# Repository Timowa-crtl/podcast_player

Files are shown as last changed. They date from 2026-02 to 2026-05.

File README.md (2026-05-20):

# KnobFM

Turn your Raspberry Pi into a tactile podcast and music player. Assign your podcasts and albums to fixed knob positions — turn to select, flip to play.

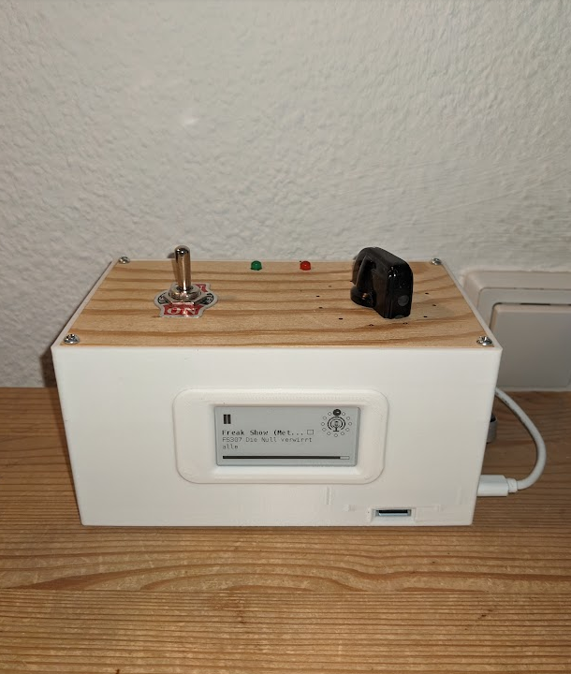
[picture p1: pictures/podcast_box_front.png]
frontview of 3D-printed enclosure


## How it works

- A **12-position rotary knob** selects one of up to 12 podcast feeds (Podcast mode) or up to 12 album folders (Music mode).
- A **3-position mode switch** toggles between **Podcast / Paused / Music**.
- Playback position is **auto-saved**, so switching modes or rebooting resumes where you left off.
- Audio plays through **VLC → ALSA** out of the Pi's 3.5 mm jack.
- Two **status LEDs** show what the player is doing (green = playing or activity, red = warning/error).
- New podcast episodes are fetched **hourly**.
- An optional **Waveshare 2.13″ e-ink display** shows the current podcast/album, episode title, and a progress bar.

## Hardware

The player needs:

- A Raspberry Pi (3 B/B+, 2 B, or 1 B+)
- A 12-position rotary switch (one GPIO per position, active-low)
- A 3-position toggle switch for the mode
- Two LEDs (red + green) with current-limiting resistors
- _(Optional)_ a Waveshare 2.13″ V2/V3 e-ink HAT

See:

- **[HARDWARE.md](HARDWARE.md)** — full bill of materials (Pi model, switches, LEDs, e-ink, enclosure, wiring supplies)
- **[WIRING.md](WIRING.md)** — GPIO pin assignments for the rotary switch, mode switch, LEDs, and optional e-ink display

**Audio output:** My recommended setup is a 3.5 mm in-car FM transmitter plugged into the Pi's aux output, broadcasting to a nearby FM radio.

## Enclosure

A 3D-printed enclosure designed for this project. The enclosure includes a mounting point and port cutouts. The lid features cutouts for the 3-way switch, R26 turning knob, and two LEDs.

Download the STL files from **[Thingiverse](https://www.thingiverse.com/thing:7228464)**, or grab them from [`enclosure/`](enclosure/).

## Installation

1. **Clone the repository**

   ```bash
   git clone https://github.com/Timowa-crtl/podcast_player.git
   cd podcast_player
   ```

2. **Install system dependencies**

   ```bash
   sudo apt update
   sudo apt install vlc
   ```

3. **Install Python packages** (system-wide via apt)

   ```bash
   sudo apt install python3-requests python3-schedule python3-vlc python3-pil python3-rpi.gpio
   ```

   If `python3-schedule` is unavailable on your Raspberry Pi OS release, fall back to `sudo pip install schedule`.

4. **(Optional) E-ink display setup**
   - Enable SPI: `sudo raspi-config` → Interface Options → SPI → Enable
   - Install extras: `sudo apt install python3-spidev python3-numpy`
   - The `waveshare_epd` driver is vendored in this repo — no separate install needed.
   - If `PIL` or `waveshare_epd` is missing, the display is silently disabled and the rest of the player works normally.

## Configuration

Edit `config.json` to customize your podcasts, albums and settings.

## Usage

### Run the player

```bash
python3 main.py                  # start the player (Ctrl+C to stop)
```

### Inspect state

```bash
python3 status.py
```

### Hardware smoke tests

Run these directly on the Pi to verify wiring:

```bash
python3 hardware.py          # poll the rotary + mode switch, prints state to stdout
python3 led_controller.py    # cycle through every LED state
```

## Autostart with systemd

To run the player on boot, create a systemd service. Replace `<your-user>` with your Linux username (e.g. `pi`).

1. Create `/etc/systemd/system/podcast.service` with:

   ```ini
   [Unit]
   Description=Podcast Player
   After=network.target

   [Service]
   ExecStart=/usr/bin/python3 -u /home/<your-user>/podcast_player/main.py
   WorkingDirectory=/home/<your-user>/podcast_player
   User=<your-user>
   Restart=always

   StandardOutput=append:/home/<your-user>/podcast_player/podcast.log
   StandardError=append:/home/<your-user>/podcast_player/podcast.log

   [Install]
   WantedBy=multi-user.target

   ```

2. Reload systemd:

   ```bash
   sudo systemctl daemon-reload
   ```

3. Enable autostart:

   ```bash
   sudo systemctl enable podcast.service
   ```

4. Start service:

   ```bash
   sudo systemctl start podcast.service
   ```

5. View logs:

   ```bash
   tail -f ~/podcast_player/podcast.log
   ```

## Gallery

frontview of 3D-printed enclosure
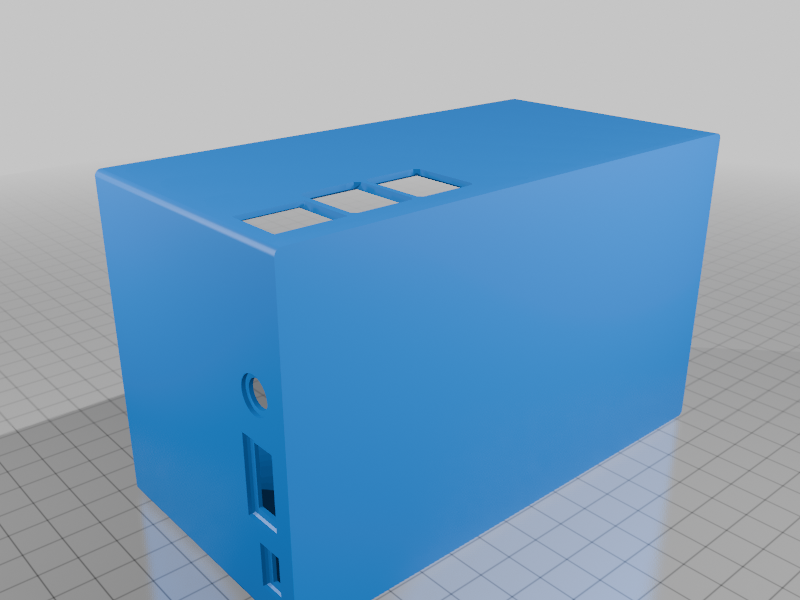
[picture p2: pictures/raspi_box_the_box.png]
enclosure box render

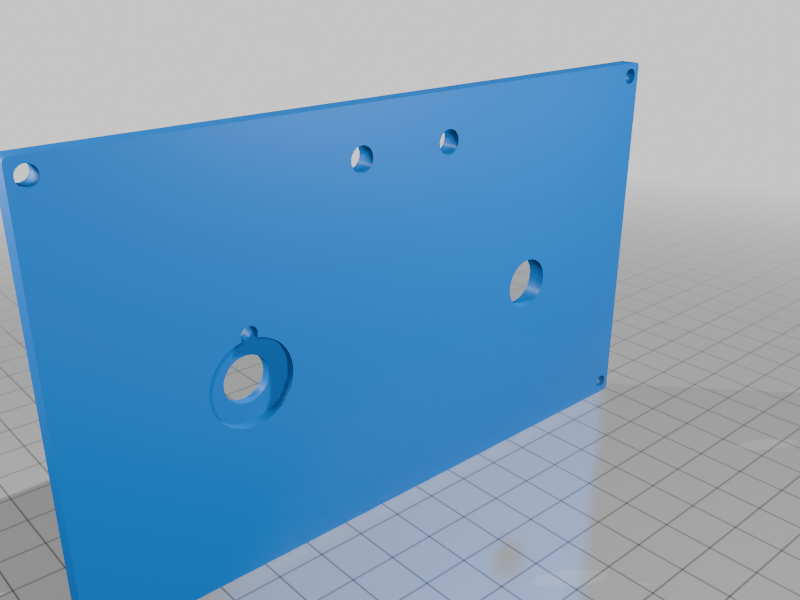
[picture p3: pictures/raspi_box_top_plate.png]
top plate render

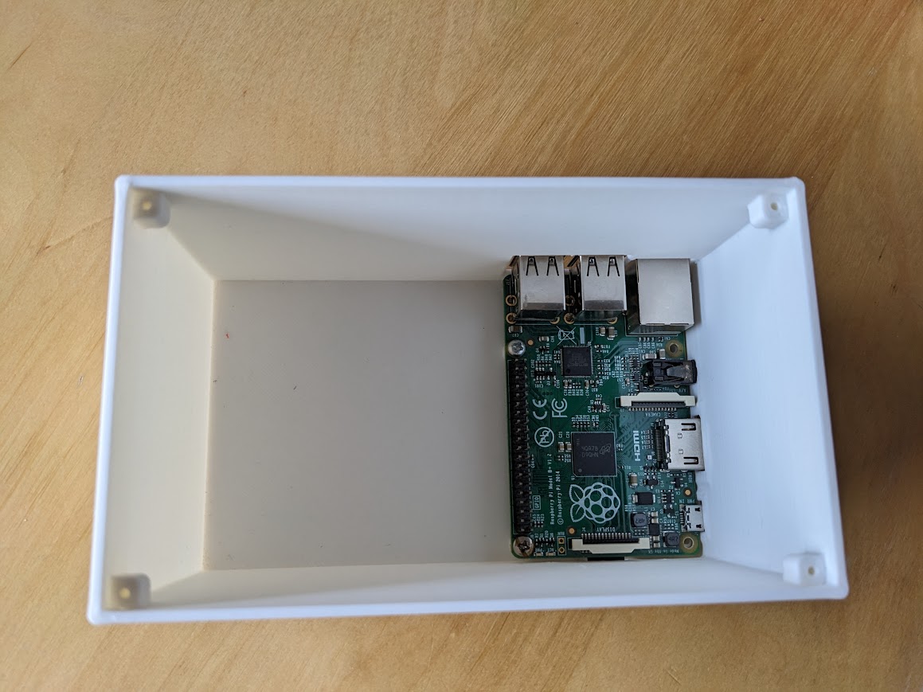
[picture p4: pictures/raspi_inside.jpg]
Raspberry Pi wired inside the enclosure

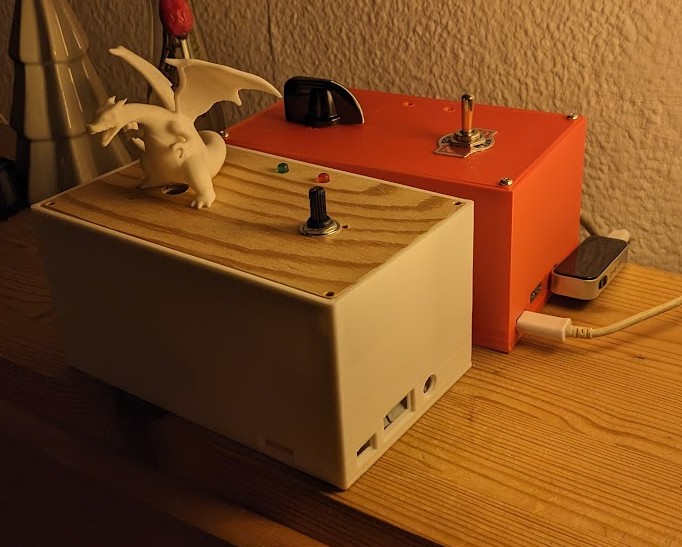
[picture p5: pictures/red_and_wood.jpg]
finished player, red knob with wood top

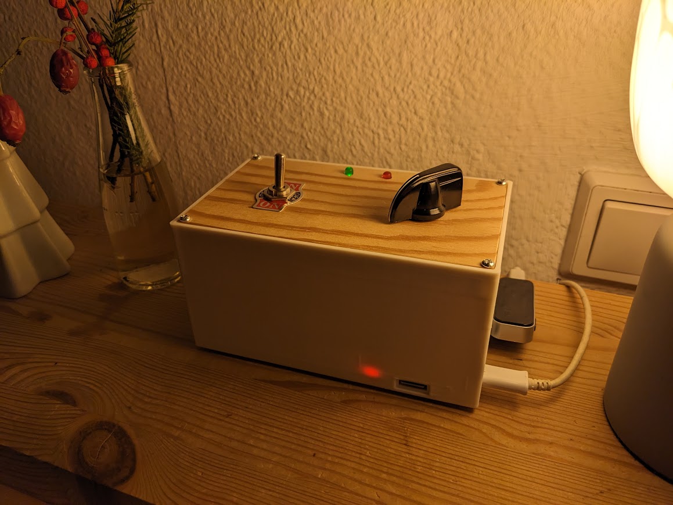
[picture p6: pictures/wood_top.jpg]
wood top plate detail


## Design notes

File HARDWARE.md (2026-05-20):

# Hardware

Bill of materials for building the player. For how to wire them up, see [WIRING.md](WIRING.md).

## Compute

- Raspberry Pi 3 B, Pi 2 B, Pi 1 B+. Any model with a 40-pin GPIO header should work.
- **MicroSD card** — 16 GB or larger

## Controls

### Rotary Switch (podcast / album selector)

- **RS26 1-pole 12-position rotary switch**, panel mount, 6 mm shaft
- **Knob** — R26-style aluminum knob with 6 mm collet (matches the enclosure cutout)

### Mode Switch (podcast / paused / music)

- **3-position SPDT toggle switch**, center-off (ON-OFF-ON), panel mount

### Status LEDs

- **2× 3 mm LEDs** — one red, one green
- **resistor** — 1000 Ω 

### Audio Output (recommended)

- **3.5 mm in-car FM transmitter** — plugs into the Pi's 3.5 mm aux output and broadcasts on an FM frequency you tune your radio to. This my recommended setup. Feel free to adapt!

### E-Ink Display (optional)

- **Waveshare 2.13" e-Paper HAT (V4)** — 250×122, SPI interface
  - The vendored driver in `waveshare_epd/` targets the V4 specifically; older V1/V2/V3 panels might need a different driver

## Connections & Prototyping

- **T-type GPIO breakout board for Raspberry Pi** — with 40-pin ribbon cable, to bring the Pi header onto a breadboard or prototype board
- **Breadboard** - must fit breakout board and cables and fit into the enclosure
- **Dupont jumper wires** — 20-pin assorted set with M-M, F-M, and F-F (Pi header → breakout → switches/LEDs)

## Enclosure

- **3D-printed case** with cutouts for the rotary knob, 3-position switch, and two LEDs
  - STL files: [thingiverse.com/thing:7228464](https://www.thingiverse.com/thing:7228464)
  - Compatible with Pi 3 B/B+, Pi 2 B, Pi 1 B+

## Wiring

See [WIRING.md](WIRING.md) for the full GPIO pin assignment table.

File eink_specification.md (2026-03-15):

# E-Ink Display Specification

## Overview

Add a Waveshare 2.13" V4 e-ink display (250×122 pixels, 1-bit black/white) to show playback status. The display is **completely optional** — the player works fine without it, same as GPIO.

---

## Hardware

- **Model**: Waveshare 2.13" V4 (epd2in13_V4)
- **Resolution**: 250×122 pixels, landscape orientation
- **Colors**: 1-bit (black and white only)
- **Interface**: SPI

---

## Screen Layout

There is **one layout** used for both playing and paused states, in both podcast and music modes. The only difference between playing and paused is the icon (▶ vs ⏸).

```
┌──────────────────────────────────────────┐
│                                  · · ·   │
│                                ·       · │
│                                ·  icon · │
│                                ·       · │
│                                  · ● ·   │
│                                          │
│ ▶ LANZ & PRECHT ☐                       │
│                                          │
│ Ausgabe 421: Über die Zukunft            │
│ der Arbeit in Deuts...                   │
│                                          │
│ ████████████████░░░░░░░░░░░░░░░░░░░░░░░ │
└──────────────────────────────────────────┘
```

### Elements top to bottom

1. **Dot circle with mode icon** (top-right): 12 dots in a circle representing the rotary knob positions, with the current position shown as a larger filled dot. A mode icon (podcast or music) is centered inside the dot circle.

2. **Name line**: play (▶) or pause (⏸) icon + podcast name or album display name (bold, truncated to fit) + completion checkbox (☐/☑) immediately after the name text.

3. **Title area**: episode title or track filename, regular weight, up to 2 lines, word-wrapped, truncated with `...` if needed.

4. **Progress bar**: full display width with margins, outlined rectangle with black fill representing progress. No text/numbers.

---

## Dot Circle (Knob Position Indicator)

A circle of 12 dots mirroring the physical 12-position rotary knob.

### Positioning

- Top-right corner of the display
- ~44px diameter (22px radius)
- Mode icon centered inside the circle

### Dot orientation

Dots are numbered 1–12 clockwise, starting from the bottom-left:

- **Position 1**: 7 o'clock (bottom-left)
- **Position 6**: 12 o'clock (top)
- **Position 12**: 6 o'clock (bottom)

### Dot rendering

- Inactive positions: small filled dot (~2px radius)
- Active position: larger filled dot (~4px radius)

### Center icon

- Podcast mode: `icons/podcast.png` (microphone with broadcast arcs)
- Music mode: `icons/music.png` (beamed eighth notes)
- Pre-made 1-bit PNGs, resized to 24×24px, stored in `icons/` directory
- If icon file is missing: skip silently, no crash

---

## Completion Checkbox

- Small checkbox (☐ unchecked / ☑ checked) drawn inline on the name line, immediately after the name text with a small gap
- ☑ = this album/podcast episode has been played to the end at least once
- ☐ = not yet completed
- The checkbox reduces the available width for the name text — name is truncated to leave room

---

## Play / Pause Icon

- **Playing**: filled triangle pointing right (▶)
- **Paused**: two vertical bars (⏸)
- Drawn at the left edge of the name line, before the name text

---

## Progress Bar

- Full display width minus left/right margins
- Thin outlined rectangle with black fill from the left representing progress (0.0–1.0)
- If duration is unknown: empty bar (outline only)

---

## Text Rendering

- **Font**: monospace TTF (DejaVu Sans Mono preferred, falls back to Liberation Mono, FreeMono, then Pillow default)
- **Name line**: bold, ~11px
- **Title lines**: regular, ~10px
- **Truncation**: names and titles truncated with `...` if they exceed available width
- **Title wrapping**: up to 2 lines, word-wrapped, last line truncated if needed
- **No scrolling, no animation, all text is static**

---

## Display States

| State | Play/pause icon | Name | Title | Checkbox | Progress | Dot circle icon |
|---|---|---|---|---|---|---|
| Podcast playing | ▶ | podcast name | episode title | completion state | position/duration | podcast |
| Podcast paused | ⏸ | podcast name | episode title | completion state | frozen | podcast |
| Music playing | ▶ | album display name | track filename | completion state | position/duration | music |
| Music paused | ⏸ | album display name | track filename | completion state | frozen | music |
| Album completed | ⏸ | album display name | last track filename | ☑ | full | music |
| No episode | ⏸ | podcast name | "Error - no episode found" | ☐ | empty | podcast |
| Blank | — | — | — | — | — | — |

### Boot / no content → blank

On startup, one full refresh to clear display to white. Stays blank until the first mode change that has content to show.

### Paused with no prior playback

If the player has never played anything in this session, display stays blank. First play action triggers the first draw.

---

## Update Triggers

| Event | Display action |
|---|---|
| Mode switch to PLAYING | Redraw with ▶ + podcast info |
| Mode switch to MUSIC_MODE | Redraw with ▶ + album info |
| Mode switch to PAUSED | Redraw with ⏸, keep current content |
| Knob turn while playing | Redraw with new podcast/album |
| Knob turn while paused | Redraw with preview of new selection |
| Progress update (every 30s) | Redraw with updated progress |
| Track change (music) | Redraw with new track info |
| Album completed (music) | Show ☑ + full progress bar |
| No episode available | Show name + error title |
| RSS check running/completed | No display change (LED handles this) |
| Shutdown | Put display to sleep |

---

## Refresh Strategy

- **Partial refresh** for all normal updates (~0.3s)
- **One full refresh on startup** to clear ghosting
- **Periodic full refresh** every ~50 partial refreshes to reduce ghosting buildup

---

## Display Controller API

```python
class EinkDisplay:
    """E-Ink display controller. Optional — disabled if hardware missing."""

    def __init__(self, icons_dir: str = "icons"):
        """Init display. Loads icon PNGs from icons_dir.
        Sets self.available = False if libs/hardware missing."""

    def clear(self):
        """Full refresh to white. Called once on startup."""

    def show(self, name: str, title: str, progress: float,
             knob_position: int, is_playing: bool, is_completed: bool,
             icon: Optional[str] = None):
        """
        Draw the screen. Single method for all states.

        Args:
            name:           podcast name or album display name
            title:          episode title or track filename
            progress:       0.0 to 1.0 (progress bar fill)
            knob_position:  1-12 (active dot in the circle)
            is_playing:     True = ▶, False = ⏸
            is_completed:   True = ☑, False = ☐
            icon:           "podcast", "music", or None
        """

    def show_blank(self):
        """Clear to white (partial refresh)."""

    def cleanup(self):
        """Put display to sleep. Called on shutdown."""
```

One render method. Callers pass data, display draws it.

---

## Graceful Degradation

Same pattern as `LEDController` and `HardwareController`:

- If Pillow or the Waveshare library is missing, or hardware init fails, `self.available = False`
- Every public method is a no-op if `self.available` is False
- No crashes, no errors — just silently disabled

---

## Integration Points

### podcast_player.py

Display updated from the main controller:

- `switch_to_podcast()` → `display.show(..., icon="podcast")`
- `switch_to_album()` → `display.show(..., icon="music")`
- `pause()` → `display.show(...)` with current info, `is_playing=False`, same icon as last active mode
- `handle_switch_change()` knob turn while paused → `display.show(...)` with preview info
- `_on_track_ended()` → redraw with new track info
- Main loop every 30s during playback → `display.show(...)` with updated progress

### Progress update in main loop

```python
# In run(), alongside existing polling:
if self.audio.is_playing() and time.time() - last_display_update > 30:
    self._update_display()
    last_display_update = time.time()
```

---

## Demo Mode

Run `python eink_display.py` to cycle through display states on the real e-ink screen. **Requires hardware** — exits immediately if no display is detected.

- Cycles 8 screens (20 seconds each): podcast playing, podcast paused (completed), music playing, music paused, album completed, no episode error, long name truncation, position 12 test
- Loops until Ctrl+C
- Blank screen shown between cycles
- On exit: clears display and puts it to sleep

---

## Edge Cases

### Album completed

When the last track finishes, the player goes silent. The display stays on and shows the completed album with ☑ checkbox, album name, last track filename, and a **full progress bar**. Remains until the user switches away.

### No episode available

If a podcast position has no downloaded episode, the display shows the podcast name with title `"Error - no episode found"` and an empty progress bar.

### Music track change

When one track ends and the next begins, the display briefly shows the **completed track with a full progress bar** (one refresh cycle), then redraws with the new track's filename and an empty progress bar.

### RSS check

Display ignores RSS checks entirely. LED handles that feedback.

---

## File Summary

| File | Change | Description |
|---|---|---|
| `eink_display.py` | **NEW** | Display controller: rendering, refresh, layout, demo |
| `icons/podcast.png` | **NEW** | 1-bit podcast icon (24×24px, white background) |
| `icons/music.png` | **NEW** | 1-bit music icon (24×24px, white background) |
| `podcast_player.py` | MODIFIED | Call `display.show()` on mode/knob/progress changes |
| `requirements.txt` | MODIFIED | Add `Pillow` (waveshare lib is vendored) |

---

## Scope Exclusions

- No clock
- No scrolling text
- No animations
- No overview/list screen
- No configuration options for display
- No different layouts per mode (one layout fits all)
- No track number display (just filename)
- No display feedback for RSS checks, warnings, or errors (LED handles those)
- No PNG export in demo mode — demo requires real hardware

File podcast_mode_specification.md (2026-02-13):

# Podcast Mode Specification

## Overview

The Raspberry Pi Podcast Player supports up to 12 podcast feeds mapped to the 12-position rotary knob. In podcast mode, the player fetches episodes via RSS, downloads audio files, and plays them with persistent position tracking. Episodes are checked periodically and old ones are cleaned up automatically.

---

## Configuration

### config.json

```json
{
  "podcasts": [
    {
      "name": "Logbuch Netzpolitik",
      "rss_url": "https://logbuch-netzpolitik.de/feed/mp3"
    },
    {
      "name": "Radiolab",
      "rss_url": "https://feeds.simplecast.com/EmVW7VGp"
    }
  ],
  "episodes_dir": "episodes",
  "max_episodes_per_podcast": 2,
  "check_interval_hours": 1,
  "position_save_interval": 1,
  "download_timeout": 30,
  "rss_timeout": 10,
  "debug_mode": false
}
```

- `podcasts`: list of up to 12 entries, mapped to knob positions 1–12 in order
  - `name`: required, display name
  - `rss_url`: required, RSS feed URL
- `episodes_dir`: where downloaded episodes are stored. **Default**: `episodes`
- `max_episodes_per_podcast`: max episodes kept per feed. **Default**: `2`
- `check_interval_hours`: how often to check RSS feeds. **Default**: `1`
- `position_save_interval`: seconds between position saves. **Default**: `5`
- `download_timeout`: seconds before download times out. **Default**: `30`
- `rss_timeout`: seconds before RSS fetch times out. **Default**: `10`
- `debug_mode`: enable verbose DEBUG-level logging. **Default**: `false`

### Validation

- `podcasts` must be present and non-empty
- Maximum 12 podcasts
- Each podcast must have `name` and `rss_url`

---

## RSS Feed Handling

### Fetching

- Standard HTTP GET with `User-Agent: PodcastPlayer/1.0`
- Supports both RSS 2.0 (`<item>`) and Atom (`<entry>`) feeds
- Timeout controlled by `rss_timeout`

### Episode extraction

From each feed item, extract:

- **Title**: from `<title>` element. Whitespace-collapsed, truncated to 100 chars
- **Audio URL**: from `<enclosure url="...">` (RSS) or `<link rel="enclosure" href="...">` (Atom)
- **GUID**: from `<guid>` or `<id>`. Falls back to audio URL if missing

Items without an enclosure URL are skipped.

### Check schedule

- First check runs immediately on startup
- Subsequent checks run every `check_interval_hours` via the `schedule` library
- Checks also run pending in the main loop (polled every 100ms)

---

## Episode Downloading

### File naming

Episodes are saved as `episode_<hash>.mp3` where `<hash>` is the first 12 hex chars of the MD5 of the episode GUID. This gives stable filenames across restarts.

### Storage layout

```
episodes/
  podcast_1/
    episode_abc123def456.mp3
  podcast_2/
    episode_789012345678.mp3
```

Each podcast gets its own subdirectory under `episodes_dir`.

### Download behavior

- Streamed download in 8KB chunks
- Progress logged at DEBUG level every 10%
- If the file already exists (same GUID hash), download is skipped
- Partial downloads are deleted on failure

### Cleanup

After updating episodes for a podcast, any files in that podcast's directory that aren't in the current episode list are deleted. This keeps storage bounded to `max_episodes_per_podcast` files per feed.

---

## Playback Behavior

### Basic flow

1. Switch to Podcast mode → start playing the podcast at the current knob position
2. Plays the current episode from the saved position
3. One episode per podcast at a time (controlled by `current_index`)

### Resume

- Switching away and back to a podcast **resumes exact position**
- Resume rewinds 2 seconds for context (`pos = max(0, ep["position"] - 2)`)
- Position saved at `position_save_interval` via a background thread in `AudioPlayer`
- If the episode is within 10 seconds of the end, it restarts from the beginning

### Switching podcasts

- Turning the knob while in Podcast mode → **immediately stop current, start new podcast**
- If knob is on position 3 and user switches from Music/Pause to Podcast → **immediately start podcast 3**

### Error handling

- No episodes downloaded yet → log warning, stay silent, LED off
- Episode file missing from disk → log error, stay silent, LED off
- RSS fetch timeout or parse error → log warning/error, skip that feed
- Download timeout or HTTP error → log error, clean up partial file, skip

---

## State Storage

Stored in `state.json` under the `podcasts` namespace.

```json
{
  "version": 2,
  "podcasts": {
    "podcast_1": {
      "episodes": [
        {
          "title": "Episode Title",
          "guid": "unique-episode-id",
          "file": "episode_abc123def456.mp3",
          "position": 123.4,
          "last_played": "2025-01-15T10:30:00",
          "completed": false
        }
      ],
      "current_index": 0,
      "total_time": 3600
    }
  },
  "music": { ... },
  "last_check": 1705312200
}
```

- `episodes`: ordered list of downloaded episodes
- `current_index`: which episode is active (0-based)
- `total_time`: cumulative listening time in seconds (incremented by 1 per save tick)
- `position`: seconds into the episode
- `completed`: true when episode finished
- `last_check`: Unix timestamp of last RSS check (shared across all feeds)

### Position save throttling

`StateManager.save()` is throttled to at most once per second unless `force=True`.

---

## Hardware / Switch Mapping

### 3-position mode switch

| Position | Behavior |
| --- | --- |
| Play | Play podcast at current knob position |
| Center | Paused (both modes) |
| Music | Play music (see music_mode_specification.md) |

### 12-position rotary knob

- In Podcast mode: selects podcast 1–12
- Debounced: requires 3 stable reads and 200ms minimum between changes

### LED behavior

| State | LEDs |
| --- | --- |
| Playing | Green solid  |
| Paused | Off |
| Checking RSS | Green blink  |
| Downloading  | Green blink  |
| Warning | Red 3× blink |
| Error | Red 5× blink |

---

## Software-only Mode (no GPIO)

Without GPIO (e.g. running on a desktop), the hardware controller returns `PAUSED` with no podcast index. Podcast mode is not reachable without hardware or manual code changes.

---

## Status Display (status.py)

```
📻 Podcasts (12):
   1. Logbuch Netzpolitik
   2. Fest und Flauschig
   ...

📚 Podcast Episodes:

   Logbuch Netzpolitik:
      ▶️ 1. LNP500: Jubiläumsfolge         | 1h 23m 45s | 45.2 MB
      ✅ 2. LNP499: Alte Folge              | 0s         | 38.1 MB

💾 Storage: 24 files, 1234.5 MB in episodes
💿 Disk: 12.3 GB free / 32.0 GB (62% used)
```

Markers: `▶️` = current episode, `✅` = completed, blank = not yet played.

---

## Scope

- One episode plays at a time per podcast (no playlist/queue)
- No episode skipping via hardware
- No per-podcast volume control
- No streaming — episodes are fully downloaded before playback
- mp3 only (determined by RSS enclosure)

---

## File Summary

| File | Role |
| --- | --- |
| `config.py` | Loads and validates `config.json` |
| `config.json` | Podcast list, directories, timeouts |
| `podcast_manager.py` | RSS fetching, episode downloading, cleanup |
| `audio_player.py` | VLC playback with position tracking |
| `state_manager.py` | Persistent JSON state for positions and metadata |
| `podcast_player.py`  | Main controller: ties hardware → podcast/music → audio |
| `hardware.py` | GPIO rotary switch and mode switch reading |
| `led_controller.py`  | Red/green LED patterns for status feedback |
| `status.py` | CLI status display tool |
| `main.py` | Entry point, signal handling, startup/shutdown |
| `utils.py` | Logging, formatting helpers |

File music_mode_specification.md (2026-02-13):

# Music Mode Specification

## Overview

Add a music playback mode to the Raspberry Pi Podcast Player. The 3-position switch becomes: **PlayPodcast / Pause / PlayMusic**. In music mode, each of the 12 rotary knob positions selects an album folder and plays it sequentially from track 1 to end, remembering position across switches.

---

## Configuration

### config.json additions

```json
{
  "music_dir": "/home/tweckerle/music",
  "albums": [
    { "folder": "Kraftklub - Mit K.-2012" },
    { "folder": "Linkin Park - Meteora", "name": "Meteora" },
    { "folder": "Peter Fox - Stadtaffe" }
  ]
}
```

- `music_dir`: base directory for album folders. **Default**: `~/music`
- `albums`: list of up to 12 entries, mapped to knob positions 1-12 in order
- `folder`: required, relative to `music_dir`
- `name`: optional display name override. **Default**: folder name

### Album discovery fallback

If `albums` is **not present or empty** in config.json, auto-discover by taking the first 12 subfolders of `music_dir` sorted alphabetically. If `albums` is configured, use only those — no auto-discovery.

### Config reading

Music config is **re-read from config.json on every knob selection** (not cached at startup). This allows editing config without restarting the player.

---

## File Handling

- **Format**: mp3 only (`.mp3` extension, case-insensitive)
- **Sorting**: natural/numeric sort (e.g., `2-song.mp3` before `10-song.mp3`)
- **Subfolder handling**: top-level files only, no recursion into subdirectories
- **Track discovery**:
  - **Fresh start / album reset**: scan folder for all mp3 files at play time
  - **Resuming saved position**: use remembered track list, do not re-scan

---

## Playback Behavior

### Basic flow

1. Switch to Music mode → start playing the album at the current knob position
2. Tracks play sequentially from track 1 to last track
3. Standard gap between tracks (no crossfade, no gapless)
4. Track changes logged at INFO level: `"Now playing track 3/12: filename.mp3"`

### Resume

- Switching away and back to an album **resumes exact track + position within track**
- Switching from Pause to Music **resumes** where it left off
- Position saved at same `position_save_interval` as podcasts (configurable, currently 1s)
- Resume rewinds 2 seconds (same as podcast behavior)

### Album completed

- After last track ends → **stop playback, go silent**
- Album marked as completed in state
- When a completed album is selected again (or switched back to) → **reset to track 1, position 0, re-scan folder for mp3 files**

### Switching albums

- Turning knob while in Music mode → **immediately stop current album, start new album**
- If knob is on position 7 and user switches from Podcast to Music → **immediately start album 7**

### Error handling

- Missing/empty album folder → log warning, play nothing
- Corrupted/unplayable mp3 → log warning, mark track as completed, skip to next track
- If all tracks fail → album goes silent (treated as completed)

### Positions 9-12 with fewer albums

- If fewer than 12 albums configured/discovered → unassigned positions do nothing (silence, log warning)

---

## State Storage

Stored in **same `state.json`** as podcasts, namespaced with `music_` prefix.

```json
{
  "podcasts": { ... },
  "music_1": {
    "folder": "Kraftklub - Mit K.-2012",
    "tracks": ["01-song.mp3", "02-song.mp3"],
    "current_track": 1,
    "position": 45.2,
    "completed": false,
    "total_time": 3600
  },
  "music_5": { ... }
}
```

- `folder`: the folder name at time of last play (to detect config changes)
- `tracks`: ordered list of mp3 files from last scan
- `current_track`: index into `tracks` (0-based)
- `position`: seconds into current track
- `completed`: true when last track finished
- `total_time`: cumulative listening time

---

## Hardware / Switch Mapping

### 3-position mode switch (updated)

| Position | Old behavior | New behavior |
|---|---|---|
| Play | Play podcast | **Play podcast** |
| Center | Paused | **Paused** (both modes) |
| Music | Lightshow | **Play music** |

### 12-position rotary knob

- In Podcast mode: selects podcast 1-12 (unchanged)
- In Music mode: selects album 1-12

### LED behavior (updated)

- Music mode uses **same LED behavior as podcast mode**:
  - Playing → green solid
  - Paused → off
- **Lightshow removed**

---

## Software-only mode (no GPIO)

Same behavior as podcast mode: falls back to PAUSED. Music mode not reachable without hardware (same limitation as current podcast mode).

---

## Status Display (status.py)

Show music mode info alongside podcast info:

```
🎵 Music Albums (3 configured, base: /home/tweckerle/music):
   1. Kraftklub - Mit K.-2012
      ▶️ Track 3/12 | 2m 15s | 01-intro.mp3
   2. Linkin Park - Meteora (Meteora)
      ✅ Completed
   3. Peter Fox - Stadtaffe
      (not started)
```

---

## Scope exclusions

- No track skipping (plays straight through)
- No per-mode volume control (system/VLC global volume)
- No crossfade or gapless playback
- No recursive subfolder scanning
- No file formats other than mp3

---

## Implementation constraints

- **Must not break existing podcast mode** — podcast mode is stable
- Reuse existing components where possible (`AudioPlayer`, `StateManager`, `LEDController`)
- Music state uses same `state.json`, same `position_save_interval`
- Music config re-read from `config.json` on each knob selection

---

## Implementation Summary

### Files changed

| File | Change | Description |
|---|---|---|
| `music_manager.py` | **NEW** | Album discovery, track scanning, config re-reading, natural sort |
| `audio_player.py` | MODIFIED | Added VLC `MediaPlayerEndReached` event → `has_ended()` method |
| `config.py` | MODIFIED | Added `music_dir`, `albums` properties + validation |
| `config.json` | MODIFIED | Added `music_dir`, `albums` fields |
| `state_manager.py` | MODIFIED | Added `music` namespace + `get_music`, `save_music`, `update_music_position`, `mark_music_completed`, `reset_music` methods |
| `podcast_player.py` | MODIFIED | Added music mode handling: `switch_to_album`, `_play_music_track`, `_advance_music_track`, end-of-track check in main loop |
| `led_controller.py` | MODIFIED | Removed lightshow, `MUSIC_MODE` → green solid (same as `PLAYING`) |
| `status.py` | MODIFIED | Added music albums section to status display |
| `hardware.py` | UNCHANGED | `SwitchState.MUSIC_MODE` already existed |
| `main.py` | UNCHANGED | No changes needed |
| `utils.py` | UNCHANGED | No changes needed |

### Key design decisions

1. **End-of-track detection**: VLC `MediaPlayerEndReached` event sets a `threading.Event`. Main loop polls `audio.has_ended()` every 100ms to advance tracks. Avoids complex callback threading.
2. **Config re-read**: `MusicManager._read_music_config()` reads `config.json` fresh on every knob selection. This is intentional — allows editing albums without restart.
3. **State namespacing**: Music state stored under `state["music"]["music_1"]` etc., separate from `state["podcasts"]`. Clean separation.
4. **Position callback routing**: Single `_save_position` callback checks `self._is_music_mode()` to route to podcast or music save logic.
5. **Podcast mode untouched**: All podcast logic paths remain identical. Music mode is additive only.

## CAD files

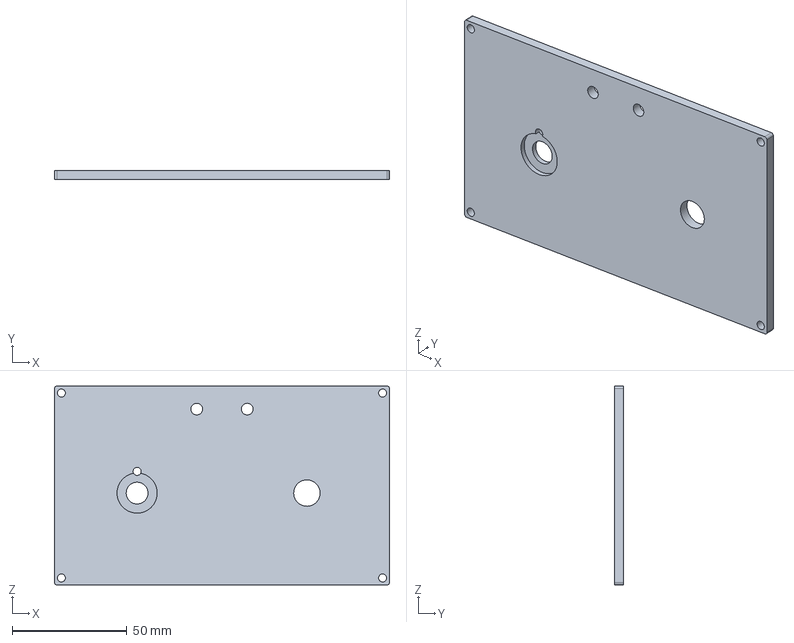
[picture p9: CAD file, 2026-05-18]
enclosure/raspi_box_base.FCStd
146.0 x 4.00 x 86.6 mm

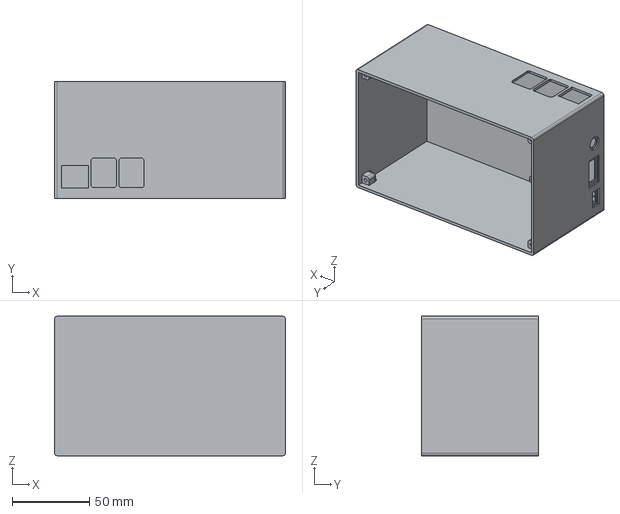
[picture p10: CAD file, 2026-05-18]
enclosure/raspi_box_the_box.step
150.0 x 76.0 x 90.6 mm

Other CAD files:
enclosure/raspi_box_top_plate.step
enclosure/raspi_box_the_box.stl
enclosure/raspi_box_top_plate.stl

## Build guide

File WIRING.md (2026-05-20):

# Wiring

All pin numbers are **BCM GPIO** (not physical header positions). Use a Raspberry Pi pinout reference (e.g. `pinout` command or [pinout.xyz](https://pinout.xyz)) to map BCM numbers to physical pins.

I used dupont wires (no soldering).

> ⚠️ **Disclaimer:** Please confirm pin positions against the source files: `hardware.py`, `led_controller.py`, and `eink_display.py`.

## 12-Position Rotary Switch

One common pole wired to **GND**. Each of the 12 positions connects to one GPIO pin:

| Position | BCM GPIO |
| --- | --- |
| 1 | 4 |
| 2 | 18 |
| 3 | 22 |
| 4 | 23 |
| 5 | 9 |
| 6 | 21 |
| 7 | 5 |
| 8 | 6 |
| 9 | 12 |
| 10 | 13 |
| 11 | 16 |
| 12 | 20 |

## 3-Position Mode Switch

Common pole to **GND**. The two outer positions connect to GPIO pins; the center position leaves both pins floating (interpreted as PAUSED).

| Position | BCM GPIO | Meaning |
| --- | --- | --- |
| Left | 7 | Podcast play |
| Center | — | Paused |
| Right | 27 | Music mode |

## LEDs

You can wire both LED cathodes (short leg) through a single **1000 Ω resistor** to **GND**. Anodes (long leg) connect directly to their GPIO pins.

| LED | BCM GPIO |
| ----- | --- |
| Red | 26 |
| Green | 19 |

## E-Ink Display (Waveshare 2.13" V4) — optional

Requires SPI enabled (`sudo raspi-config` → Interface Options → SPI).

| Display Pin | BCM GPIO / Function |
| --- | --- |
| VCC | 3.3V |
| GND | GND |
| DIN (MOSI)  | 10 (SPI MOSI) |
| CLK (SCK) | 11 (SPI SCLK) |
| CS | 8 (SPI CE0) |
| DC | 25 |
| RST | 17 |
| BUSY | 24 |

## Audio Output

Audio is played through ALSA — use the Pi's 3.5mm jack.

## Test the Wiring

```bash
python3 hardware.py      # Live readout of switch states
python3 led_controller.py # Cycle through LED patterns
```

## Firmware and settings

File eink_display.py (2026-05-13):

"""E-Ink display controller for Waveshare 2.13" V4 (250x122, 1-bit).

Layout (see specs.md for full details):
  - Top-left: play/pause icon (own line)
  - Top-right: dot circle (12 dots mimicking rotary knob) with mode icon centered inside
  - Name line: name (bold) + completion checkbox, width restricted to avoid dot circle
  - Title: up to 2 lines, word-wrapped, truncated with '...'
  - Progress bar: full width, bottom

Completely optional — gracefully disabled if hardware or libs are missing.
"""

import math
import os
import sys
import time
from typing import Optional

from utils import log

# --- Dependency detection -------------------------------------------------

_libdir = os.path.join(os.path.dirname(os.path.realpath(__file__)), "lib")
if os.path.exists(_libdir):
    sys.path.insert(0, _libdir)

try:
    from PIL import Image, ImageDraw, ImageFont

    PIL_AVAILABLE = True
except ImportError:
    PIL_AVAILABLE = False

try:
    from waveshare_epd import epd2in13_V4

    EPD_AVAILABLE = True
except ImportError:
    EPD_AVAILABLE = False

DISPLAY_AVAILABLE = PIL_AVAILABLE and EPD_AVAILABLE

if not PIL_AVAILABLE:
    log("DEBUG", "Pillow not available — e-ink display disabled")
if not EPD_AVAILABLE:
    log("DEBUG", "waveshare_epd not available — e-ink display disabled")


# --- Display dimensions ---------------------------------------------------

WIDTH = 250
HEIGHT = 122

# --- Layout constants (pixels) --------------------------------------------

MARGIN = 7

# Dot circle (top-right) — bigger radius, bigger dots
DOT_CIRCLE_RADIUS = 25
DOT_CIRCLE_CX = WIDTH - MARGIN - DOT_CIRCLE_RADIUS - 2
DOT_CIRCLE_CY = MARGIN + DOT_CIRCLE_RADIUS + 2
DOT_RADIUS_INACTIVE = 3
DOT_RADIUS_ACTIVE = 5

# Play/pause icon (top-left, own line above the name)
PLAY_ICON_SIZE = 20
PLAY_ICON_X = MARGIN
PLAY_ICON_Y = 14

# Name line (below play/pause icon, tight gap)
NAME_Y = 46

# Title (below name)
TITLE_Y = 62
TITLE_LINE2_Y = 78

# Progress bar
BAR_Y = 106
BAR_HEIGHT = 6
BAR_WIDTH = WIDTH - 2 * MARGIN

# Completion checkbox
CHECK_SIZE = 10
CHECK_GAP = 5

# Font sizes — slightly larger for readability
FONT_SIZE_NAME = 14
FONT_SIZE_TITLE = 12

# Full refresh interval (partial refreshes between full refreshes)
FULL_REFRESH_INTERVAL = 100


class EinkDisplay:
    """E-Ink display controller. Optional — disabled if hardware missing."""

    def __init__(self, icons_dir: str = "icons"):
        self.available = False
        self._partial_count = 0
        self._icons = {}
        self._font_path: Optional[str] = None

        if not DISPLAY_AVAILABLE:
            log("DEBUG", "E-ink display not available")
            return

        try:
            self.epd = epd2in13_V4.EPD()
            self.epd.init()
            self.epd.Clear(0xFF)
            self.available = True
            log("INFO", "E-ink display initialized (250x122)")
        except Exception as e:
            log("WARNING", f"E-ink init failed: {e}")
            return

        # Load fonts
        self._font_name = self._load_font(FONT_SIZE_NAME, bold=True)
        self._font_title = self._load_font(FONT_SIZE_TITLE)

        # Load mode icons from PNG files
        self._load_icons(icons_dir)

    # --- Font loading ------------------------------------------------------

    def _load_font(self, size: int, bold: bool = False):
        """Load a monospace TTF font, falling back to Pillow default."""
        candidates = []

        if bold:
            candidates += [
                "/usr/share/fonts/truetype/dejavu/DejaVuSansMono-Bold.ttf",
                "/usr/share/fonts/truetype/liberation/LiberationMono-Bold.ttf",
                "/usr/share/fonts/truetype/freefont/FreeMonoBold.ttf",
            ]

        candidates += [
            "/usr/share/fonts/truetype/dejavu/DejaVuSansMono.ttf",
            "/usr/share/fonts/truetype/liberation/LiberationMono-Regular.ttf",
            "/usr/share/fonts/truetype/freefont/FreeMono.ttf",
        ]

        for path in candidates:
            if os.path.exists(path):
                try:
                    font = ImageFont.truetype(path, size)
                    if self._font_path is None:
                        self._font_path = path
                    return font
                except Exception:
                    continue

        log("DEBUG", f"No TTF font found, using Pillow default (size={size})")
        return ImageFont.load_default()

    # --- Icon loading ------------------------------------------------------

    # Icon size — PNGs are resized to this square dimension to fit inside the dot circle
    ICON_SIZE = 35

    def _load_icons(self, icons_dir: str):
        """Load 1-bit PNG icons from the icons directory.

        Expected files: icons/podcast.png, icons/music.png
        Icons are resized to ICON_SIZE x ICON_SIZE and converted to 1-bit.
        Missing icons are silently skipped.
        """
        from pathlib import Path

        icons_path = Path(icons_dir)
        if not icons_path.is_dir():
            log("DEBUG", f"Icons directory not found: {icons_dir}")
            return

        for name in ("podcast", "music"):
            icon_file = icons_path / f"{name}.png"
            if not icon_file.exists():
                log("DEBUG", f"Icon not found: {icon_file}")
                continue
            try:
                img = Image.open(icon_file).convert("1")
                img = img.resize(
                    (self.ICON_SIZE, self.ICON_SIZE), Image.Resampling.NEAREST
                )
                self._icons[name] = img
                log("DEBUG", f"Loaded icon: {name} ({self.ICON_SIZE}x{self.ICON_SIZE})")
            except Exception as e:
                log("WARNING", f"Failed to load icon {name}: {e}")

    # --- Public API --------------------------------------------------------

    def clear(self):
        """Full refresh to white. Called once on startup."""
        if not self.available:
            return
        try:
            self.epd.init()
            self.epd.Clear(0xFF)
            self._partial_count = 0
            log("DEBUG", "Display cleared (full refresh)")
        except Exception as e:
            log("ERROR", f"Display clear failed: {e}")

    def show(
        self,
        name: str,
        title: str,
        progress: float,
        knob_position: int,
        is_playing: bool,
        is_completed: bool,
        icon: Optional[str] = None,
    ):
        """
        Draw the screen. Single method for all states.

        Args:
            name:           podcast name or album display name
            title:          episode title or track filename
            progress:       0.0 to 1.0 (progress bar fill)
            knob_position:  1-12 (active dot in the circle)
            is_playing:     True = play icon, False = pause icon
            is_completed:   True = checked box, False = unchecked box
            icon:           "podcast", "music", or None
        """
        if not self.available:
            return

        try:
            image = self._render(
                name, title, progress, knob_position, is_playing, is_completed, icon
            )
            self._display(image)
        except Exception as e:
            log("ERROR", f"Display show failed: {e}")

    def show_blank(self):
        """Clear to white (partial refresh)."""
        if not self.available:
            return
        try:
            image = Image.new("1", (WIDTH, HEIGHT), 255)
            self._display(image)
        except Exception as e:
            log("ERROR", f"Display show_blank failed: {e}")

    def cleanup(self):
        """Put display to sleep. Called on shutdown."""
        if not self.available:
            return
        try:
            self.epd.sleep()
            log("DEBUG", "Display entered sleep mode")
        except Exception as e:
            log("DEBUG", f"Display cleanup: {e}")

    # --- Layout helpers ----------------------------------------------------

    def _max_text_width(self, text_y: int, text_height: int = 14) -> int:
        """Return max text width at the given Y, shrinking if the dot circle is alongside.

        Any text line that overlaps vertically with the dot circle bounding box
        is shortened so it doesn't collide. Lines fully below the circle get
        the full display width.
        """
        # Dot circle bounding box (with a small padding)
        dot_top = DOT_CIRCLE_CY - DOT_CIRCLE_RADIUS - DOT_RADIUS_ACTIVE - 4
        dot_bottom = DOT_CIRCLE_CY + DOT_CIRCLE_RADIUS + DOT_RADIUS_ACTIVE + 4
        dot_left = DOT_CIRCLE_CX - DOT_CIRCLE_RADIUS - DOT_RADIUS_ACTIVE - 6

        text_bottom = text_y + text_height
        full_width = WIDTH - 2 * MARGIN

        # If this text line overlaps vertically with the dot circle, restrict width
        if text_bottom > dot_top and text_y < dot_bottom:
            return dot_left - MARGIN
        return full_width

    # --- Rendering ---------------------------------------------------------

    def _render(
        self, name, title, progress, knob_position, is_playing, is_completed, icon
    ):
        """Render all elements onto a 1-bit PIL Image."""
        image = Image.new("1", (WIDTH, HEIGHT), 255)
        draw = ImageDraw.Draw(image)

        # 1. Dot circle with mode icon (top-right)
        # 1.1 Mode icon FIRST (background layer)
        if icon and icon in self._icons:
            self._paste_mode_icon(image, DOT_CIRCLE_CX, DOT_CIRCLE_CY, icon)
        # 1.2 Dot circle ON TOP (foreground layer)
        self._draw_dot_circle(
            draw, DOT_CIRCLE_CX, DOT_CIRCLE_CY, DOT_CIRCLE_RADIUS, knob_position
        )

        # 2. Play/pause icon (top-left, own line)
        if is_playing:
            self._draw_play_icon(draw, PLAY_ICON_X, PLAY_ICON_Y)
        else:
            self._draw_pause_icon(draw, PLAY_ICON_X, PLAY_ICON_Y)

        # 3. Name + completion checkbox (dynamically avoids dot circle)
        max_name_w = self._max_text_width(NAME_Y) - CHECK_SIZE - CHECK_GAP - 2
        truncated_name = self._truncate_text(name, self._font_name, max_name_w)
        draw.text((MARGIN, NAME_Y), truncated_name, font=self._font_name, fill=0)

        name_text_w = self._get_text_width(truncated_name, self._font_name)
        check_x = MARGIN + name_text_w + CHECK_GAP
        check_y = NAME_Y + 1
        self._draw_checkbox(draw, check_x, check_y, CHECK_SIZE, is_completed)

        # 4. Title (up to 2 lines, first line width-restricted if overlapping dot circle)
        max_title_w_line1 = self._max_text_width(TITLE_Y)
        max_title_w_line2 = self._max_text_width(TITLE_LINE2_Y)
        lines = self._wrap_text_variable(
            title, self._font_title, [max_title_w_line1, max_title_w_line2]
        )
        if len(lines) >= 1:
            draw.text((MARGIN, TITLE_Y), lines[0], font=self._font_title, fill=0)
        if len(lines) >= 2:
            draw.text((MARGIN, TITLE_LINE2_Y), lines[1], font=self._font_title, fill=0)

        # 5. Progress bar
        self._draw_progress_bar(draw, MARGIN, BAR_Y, BAR_WIDTH, BAR_HEIGHT, progress)

        return image

    # --- Drawing primitives ------------------------------------------------

    def _draw_dot_circle(self, draw, cx, cy, radius, active_position):
        """Draw 12 dots in a circle. Position 1 at 7 o'clock, clockwise to 12 at 6 o'clock.
        Inactive dots are hollow, active dot is filled with its number inside.
        """
        dot_radius = 3
        active_radius = 7
        hollow_width = 1
        font_size = 3

        if self._font_path:
            try:
                num_font = ImageFont.truetype(self._font_path, font_size)
            except Exception:
                num_font = ImageFont.load_default()
        else:
            num_font = ImageFont.load_default()

        for i in range(1, 13):
            angle = (2.0 * math.pi / 3.0) + (i - 1) * (2.0 * math.pi / 12.0)
            dx = cx + math.cos(angle) * radius
            dy = cy + math.sin(angle) * radius

            if i == active_position:
                draw.ellipse(
                    [
                        dx - active_radius,
                        dy - active_radius,
                        dx + active_radius,
                        dy + active_radius,
                    ],
                    fill=0,
                    outline=0,
                )
                draw.text((dx, dy), str(i), font=num_font, fill=255, anchor="mm")
            else:
                draw.ellipse(
                    [
                        dx - dot_radius,
                        dy - dot_radius,
                        dx + dot_radius,
                        dy + dot_radius,
                    ],
                    fill=255,
                    outline=0,
                    width=hollow_width,
                )

    def _paste_mode_icon(self, image, cx, cy, icon_key):
        """Paste a pre-loaded PNG icon centered at (cx, cy) inside the dot circle."""
        icon_img = self._icons.get(icon_key)
        if icon_img is None:
            return
        x = cx - icon_img.width // 2
        y = cy - icon_img.height // 2
        image.paste(icon_img, (x, y))

    def _draw_play_icon(self, draw, x, y):
        """Filled triangle pointing right."""
        s = PLAY_ICON_SIZE
        draw.polygon(
            [(x, y), (x, y + s), (x + s, y + s // 2)],
            fill=0,
        )

    def _draw_pause_icon(self, draw, x, y):
        """Two vertical bars."""
        s = PLAY_ICON_SIZE
        bar_w = max(s // 4, 2)
        gap = s // 5
        draw.rectangle([x + gap, y, x + gap + bar_w, y + s], fill=0)
        draw.rectangle([x + s - gap - bar_w, y, x + s - gap, y + s], fill=0)

    def _draw_checkbox(self, draw, x, y, size, checked):
        """Small checkbox: outline square, with checkmark if checked."""
        draw.rectangle([x, y, x + size, y + size], outline=0, fill=255, width=1)
        if checked:
            draw.line(
                [(x + 2, y + int(size * 0.52)), (x + int(size * 0.4), y + size - 2)],
                fill=0,
                width=1,
            )
            draw.line(
                [(x + int(size * 0.4), y + size - 2), (x + size - 2, y + 2)],
                fill=0,
                width=1,
            )

    def _draw_progress_bar(self, draw, x, y, w, h, progress):
        """Outlined bar with black fill representing progress."""
        progress = max(0.0, min(1.0, progress))
        draw.rectangle([x, y, x + w, y + h], outline=0, fill=255, width=1)
        fill_w = int(w * progress)
        if fill_w > 0:
            draw.rectangle([x, y, x + fill_w, y + h], fill=0)

    # --- Text helpers ------------------------------------------------------

    def _get_text_width(self, text, font):
        """Get rendered width of text in pixels."""
        bbox = font.getbbox(text)
        return bbox[2] - bbox[0]

    def _truncate_text(self, text, font, max_width):
        """Truncate text with '...' if it exceeds max_width."""
        if self._get_text_width(text, font) <= max_width:
            return text

        for i in range(len(text), 0, -1):
            candidate = text[:i] + "..."
            if self._get_text_width(candidate, font) <= max_width:
                return candidate

        return "..."

    def _wrap_text(self, text, font, max_width, max_lines=2):
        """Break text into lines that fit within max_width (uniform width per line)."""
        return self._wrap_text_variable(text, font, [max_width] * max_lines)

    def _wrap_text_variable(self, text, font, max_widths: list):
        """Break text into lines where each line can have a different max width.

        max_widths: list of pixel widths, one per allowed line.
        Words are kept whole when possible. The last line is truncated with '...'
        if the text doesn't fit.
        """
        if not text:
            return []

        max_lines = len(max_widths)
        words = text.split()
        lines = []
        current = ""
        word_idx = 0

        while word_idx < len(words):
            line_num = len(lines)
            if line_num >= max_lines:
                break

            max_w = max_widths[line_num]
            word = words[word_idx]
            test = f"{current} {word}".strip()

            if self._get_text_width(test, font) <= max_w:
                current = test
                word_idx += 1
            else:
                if current:
                    # Current line is full, commit it
                    lines.append(current)
                    current = ""
                    # Don't advance word_idx — retry this word on the next line
                else:
                    # Single word too long for this line — truncate it
                    if line_num >= max_lines - 1:
                        # Last allowed line: truncate with remaining words
                        remaining = " ".join(words[word_idx:])
                        lines.append(self._truncate_text(remaining, font, max_w))
                        return lines[:max_lines]
                    else:
                        lines.append(self._truncate_text(word, font, max_w))
                        word_idx += 1
                        current = ""

        # Commit whatever is left
        if current and len(lines) < max_lines:
            lines.append(current)

        # Truncate last line if it overflows
        if lines:
            line_idx = len(lines) - 1
            max_w = max_widths[min(line_idx, max_lines - 1)]
            lines[-1] = self._truncate_text(lines[-1], font, max_w)

        return lines[:max_lines]

    # --- Display output ----------------------------------------------------

    def _display(self, image):
        """Send image to the e-ink display (partial or full refresh)."""
        self._partial_count += 1

        if self._partial_count >= FULL_REFRESH_INTERVAL:
            self.epd.init()
            self.epd.Clear(0xFF)
            self._partial_count = 0
            log("DEBUG", "Display full refresh (anti-ghosting)")

        buf = self.epd.getbuffer(image)

        if self._partial_count <= 1:
            # First frame after full refresh: load into both buffers
            # so partial refresh has a correct baseline (avoids dithering)
            self.epd.displayPartBaseImage(buf)
        else:
            self.epd.displayPartial(buf)


# --- Demo -----------------------------------------------------------------

DEMO_SCREENS = [
    {
        "label": "Podcast playing (pos 3, not completed)",
        "args": dict(
            name="LANZ & PRECHT",
            title="Ausgabe 421: Über die Zukunft der Arbeit in Deutschland",
            progress=0.6,
            knob_position=3,
            is_playing=True,
            is_completed=False,
            icon="podcast",
        ),
    },
    {
        "label": "Podcast paused (pos 7, completed)",
        "args": dict(
            name="Hotel Matze",
            title="Matze Hielscher im Gespräch mit Eva Schulz",
            progress=0.85,
            knob_position=7,
            is_playing=False,
            is_completed=True,
            icon="podcast",
        ),
    },
    {
        "label": "Music playing (pos 1, not completed)",
        "args": dict(
            name="OK Computer",
            title="03 - Exit Music (For a Film).mp3",
            progress=0.25,
            knob_position=1,
            is_playing=True,
            is_completed=False,
            icon="music",
        ),
    },
    {
        "label": "Music paused (pos 4, not completed)",
        "args": dict(
            name="Stadtaffe",
            title="01 - Schwarz zu Blau.mp3",
            progress=0.0,
            knob_position=4,
            is_playing=False,
            is_completed=False,
            icon="music",
        ),
    },
    {
        "label": "Album completed (pos 3, checked)",
        "args": dict(
            name="Meteora",
            title="13 - Numb.mp3",
            progress=1.0,
            knob_position=3,
            is_playing=False,
            is_completed=True,
            icon="music",
        ),
    },
    {
        "label": "No episode available (pos 2)",
        "args": dict(
            name="Fest und Flauschig",
            title="Error - no episode found",
            progress=0.0,
            knob_position=2,
            is_playing=False,
            is_completed=False,
            icon="podcast",
        ),
    },
    {
        "label": "Long name truncation (pos 9)",
        "args": dict(
            name="Aufstand Im Schlaraffenland",
            title="01 - Remmidemmi (Yippie Yippie Yeah).mp3",
            progress=0.42,
            knob_position=9,
            is_playing=True,
            is_completed=False,
            icon="music",
        ),
    },
    {
        "label": "Position 12 (bottom dot, completed)",
        "args": dict(
            name="Radiolab",
            title="The Fact of the Matter",
            progress=1.0,
            knob_position=12,
            is_playing=False,
            is_completed=True,
            icon="podcast",
        ),
    },
]
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

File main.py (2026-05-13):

#!/usr/bin/env python3
"""Raspberry Pi Podcast Player - Main Entry Point."""

import argparse
import signal
import sys

from config import Config
from podcast_player import PodcastPlayer
from utils import log, safe_cleanup


def main():
    parser = argparse.ArgumentParser(description="Raspberry Pi Podcast Player")
    parser.add_argument(
        "--skip-check",
        action="store_true",
        help="Skip the initial RSS episode check on startup",
    )
    args = parser.parse_args()

    signal.signal(signal.SIGINT, lambda *_: sys.exit(0))
    signal.signal(signal.SIGTERM, lambda *_: sys.exit(0))

    print("=" * 60)
    print("🎧 Raspberry Pi Podcast Player")
    print("=" * 60)

    player = None
    try:
        player = PodcastPlayer(Config(), skip_initial_check=args.skip_check)
        log("INFO", "🚀 Starting...")
        player.run()
    except FileNotFoundError as e:
        log("ERROR", f"Config not found: {e}")
        sys.exit(1)
    except KeyboardInterrupt:
        log("INFO", "👋 Shutting down...")
    except Exception as e:
        log("ERROR", f"Fatal: {e}")
        sys.exit(1)
    finally:
        if player:
            safe_cleanup(player.cleanup)
        log("INFO", "Shutdown complete.")


if __name__ == "__main__":
    main()

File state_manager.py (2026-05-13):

"""Persistent state storage for playback positions and episode metadata."""

import json
import time
from datetime import datetime
from pathlib import Path

from utils import log


class StateManager:
    """Manages persistent JSON state for podcast player."""

    def __init__(self, state_file: str = "state.json"):
        self.state_file = Path(state_file)
        self.state = self._load()
        self._last_save = 0.0

    def _load(self):
        """Load state from file or create default."""
        if self.state_file.exists():
            try:
                with open(self.state_file) as f:
                    state = json.load(f)
                state.setdefault("podcasts", {})
                state.setdefault("music", {})
                state.setdefault("feed_cache", {})
                state.setdefault("last_check", 0)
                return state
            except (json.JSONDecodeError, Exception) as e:
                log("ERROR", f"Error loading state: {e}")
        return {
            "version": 2,
            "podcasts": {},
            "music": {},
            "feed_cache": {},
            "last_check": 0,
        }

    def save(self, force: bool = False):
        """Save state to file (throttled unless forced)."""
        if not force and time.time() - self._last_save < 1.0:
            return
        try:
            with open(self.state_file, "w") as f:
                json.dump(self.state, f, indent=2)
            self._last_save = time.time()
        except Exception as e:
            log("ERROR", f"Failed to save state: {e}")

    # --- Feed cache (conditional GET) ---

    def get_feed_cache(self, podcast_id: str) -> dict:
        """Get cached HTTP headers for a podcast feed."""
        return self.state["feed_cache"].get(podcast_id, {})

    def save_feed_cache(self, podcast_id: str, cache: dict):
        """Save HTTP cache headers (ETag, Last-Modified) for a podcast feed."""
        # Only store non-None values
        cleaned = {k: v for k, v in cache.items() if v is not None}
        if cleaned:
            self.state["feed_cache"][podcast_id] = cleaned
        elif podcast_id in self.state["feed_cache"]:
            del self.state["feed_cache"][podcast_id]
        self.save()

    # --- Podcast state ---

    def get_podcast(self, podcast_id: str):
        """Get or create podcast state."""
        if podcast_id not in self.state["podcasts"]:
            self.state["podcasts"][podcast_id] = {
                "episodes": [],
                "current_index": 0,
                "total_time": 0,
            }
            self.save()
        return self.state["podcasts"][podcast_id]

    def update_position(self, podcast_id: str, episode_index: int, position: float):
        """Update playback position for episode."""
        podcast = self.get_podcast(podcast_id)
        if 0 <= episode_index < len(podcast["episodes"]):
            podcast["episodes"][episode_index]["position"] = position
            podcast["episodes"][episode_index][
                "last_played"
            ] = datetime.now().isoformat()
            podcast["total_time"] = podcast.get("total_time", 0) + 1
            self.save()

    def update_episode_duration(
        self, podcast_id: str, episode_index: int, duration: float
    ):
        """Store the duration (seconds) of a podcast episode once known."""
        podcast = self.get_podcast(podcast_id)
        if 0 <= episode_index < len(podcast["episodes"]):
            podcast["episodes"][episode_index]["duration"] = duration
            self.save()

    def get_episode_duration(self, podcast_id: str, episode_index: int) -> float:
        """Get stored duration for a podcast episode. Returns 0.0 if unknown."""
        podcast = self.get_podcast(podcast_id)
        if 0 <= episode_index < len(podcast["episodes"]):
            return podcast["episodes"][episode_index].get("duration", 0.0)
        return 0.0

    def set_last_check(self, timestamp: float):
        """Update last RSS check timestamp."""
        self.state["last_check"] = timestamp
        self.save(force=True)

    def get_last_check(self) -> float:
        return self.state.get("last_check", 0)

    def mark_episode_completed(self, podcast_id: str, episode_index: int):
        """Mark episode complete and advance to next."""
        podcast = self.get_podcast(podcast_id)
        if 0 <= episode_index < len(podcast["episodes"]):
            podcast["episodes"][episode_index]["completed"] = True
            podcast["episodes"][episode_index]["ever_completed"] = True
            if episode_index + 1 < len(podcast["episodes"]):
                podcast["current_index"] = episode_index + 1
            self.save(force=True)

    # --- Music state ---

    def get_music(self, music_id: str) -> dict:
        """Get music state for an album position. Returns dict or empty."""
        return self.state["music"].get(music_id, {})

    def save_music(
        self,
        music_id: str,
        folder: str,
        tracks: list,
        current_track: int,
        position: float,
        completed: bool = False,
    ):
        """Save full music state for an album position."""
        existing = self.state["music"].get(music_id, {})
        total_time = existing.get("total_time", 0)
        # Preserve track duration if already stored
        track_duration = existing.get("current_track_duration", 0.0)
        # Carry over ever_completed only if same album folder
        if existing.get("folder") == folder:
            ever_completed = existing.get("ever_completed", False)
        else:
            ever_completed = False

        self.state["music"][music_id] = {
            "folder": folder,
            "tracks": tracks,
            "current_track": current_track,
            "position": position,
            "completed": completed,
            "ever_completed": ever_completed,
            "total_time": total_time,
            "current_track_duration": track_duration,
            "last_played": datetime.now().isoformat(),
        }
        self.save()

    def update_music_position(self, music_id: str, track_index: int, position: float):
        """Update playback position for current music track."""
        ms = self.state["music"].get(music_id)
        if ms:
            ms["current_track"] = track_index
            ms["position"] = position
            ms["total_time"] = ms.get("total_time", 0) + 1
            ms["last_played"] = datetime.now().isoformat()
            self.save()

    def update_music_track_duration(self, music_id: str, duration: float):
        """Store the duration of the current music track once known."""
        ms = self.state["music"].get(music_id)
        if ms:
            ms["current_track_duration"] = duration
            self.save()
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

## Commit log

2025-10-30 v10 --> switch works! everything seems to work! resumetime slow
2025-10-30 revert to v10 vanilla
    [main.py]
2025-10-30 removed saving status in state, using switch as single source of truth i think, seems to work, no longer podcast not playing if switched to on startup
    [main.py, state_manager.py]
2025-10-31 keeping debug switch in utils and making it usable by removing shadowing default value in debug_log()
2025-10-31 removed switch_test.py, not needed
2025-10-31 inceased switch polling rate
2025-10-31 saving exact current position at pause
2025-10-31 revert, pers mpv did not work at first try
    [audio_player.py]
2025-11-18 changed to mpg123 from mpv. Test it and resume improved form 30 sec to 2 sec max. Fixed initial issue of player going mute after 30 sec of playback which seems to have been due to mpg123 pipe not bei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
    [audio_player.py, main.py]
2025-11-18 integrating 12 pin knob together with the 3-position-switch to allow selection of 12 podcasts. 12 pin knob currently not correctly read
    [audio_player.py, config.py, hardware.py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]
2025-12-08 triggering lightshow when MUSIC_MODE is selected by 3-way-switch
2025-12-08 forgot to delete old music mode logic, now triggering led show
2025-12-08 Added MUSIC_MODE = "music_mode" to the LEDState enum
    Changes made:
    Added MUSIC_MODE = "music_mode" to the LEDState enum
    Added handler for MUSIC_MODE in set_state() - does alternating red/green blink
    Added _alternate_blink() method for the light show effect
2025-12-08 Added MUSIC_MODE to the LEDState enum
    Added MUSIC_MODE to the LEDState enum
    Added _gpio_initialized flag - tracks if GPIO is ready, prevents errors after cleanup
    Added lightshow with 4 rotating patterns:
    Alternate (red ↔ green)
    Chase (both → off → red → green)
    Random flicker
    Quick pulse bursts
    Fixed cleanup errors - all LED methods now check _gpio_initialized before using GPIO
    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
    [led_controller.py]
2025-12-08 still trying to get lightshow to stop when switch position != MUSICMODE
    Fix: The pause() method now always sets self.led.set_state(LEDState.PAUSED), not just when audio is playing. This ensures the lightshow stops when switching from music mode to pause.
    Also cleaned up the music mode handler - it now properly pauses any playing podcast before starting the lightshow.
    [podcast_player.py]
2026-03-14 Remap 3 GPIO pins to free GPIO17/24/25 for e-paper display
    - Rotary position 5: GPIO24 (Pin 18) → GPIO9 (Pin 21)
    - Rotary position 6: GPIO25 (Pin 22) → GPIO21 (Pin 40)
    - Mode switch PLAY: GPIO17 (Pin 11) → GPIO7 (Pin 26)
    No logic changes. Requires rewiring 3 physical connections.
2026-03-17 trying to fix looping _try_get_duration
    [podcast_player.py]
2026-03-17 added --skip-check flag for main to make debugging easier: skipping initial podcast-update
    [main.py, podcast_player.py]
2026-03-17 bug: podcast starts podcast1 at startup, even though knob-selection is = 3 because knob position has not been pulled and system defaults to =1. added warmup.
    [podcast_player.py]
2026-03-17 doing self.epd.displayPartBaseImage(buf) after full refresh to get rid of dithering issue when using self.epd.displayPartiaf(buf) after full refresh
    [eink_display.py]
2026-03-18 trying ICON_SIZE = 35 instead of 40 (40 is slightly too big but i enjoy the extra detail
    [eink_display.py]
2026-05-13 Defer skipped RSS check, retry on idle (with staleness override)
    Previously a scheduled check that hit during playback was silently dropped,
    so heavy users could go indefinitely without updates. Now a skipped check
    is marked deferred and retried after 30s of sustained audio idle, or
    forced after 2.5h of staleness as a safety valve.
    [podcast_player.py]
2026-05-13 Format with black, fix Pylance type errors
    Apply black formatting across all .py files. In podcast_player.py,
    annotate current_* state fields as Optional, extend None-guards in
    _play_music_track and _advance_music_track so music_id and
    album_path are narrowed before being passed downstream, and drop
    an unused old_mode variable.
    [audio_player.py, eink_display.py, hardware.py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]
2026-05-13 Guard VLC Instance and MediaPlayer construction
    python-vlc's Instance() and media_player_new() are typed as
    returning Optional, so Pylance flagged every method call on
    self.instance and self.player. Raise RuntimeError on failure at
    construction time and use a locally-narrowed player variable in
    play() so the type-checker can see the non-None call sites.
    Also rename the unused VLC callback parameter to _event.
    [audio_player.py]
2026-05-13 Fix Pylance issues in eink_display
    Use Image.Resampling.NEAREST instead of the deprecated top-level
    Image.NEAREST alias, which the modern PIL stub no longer exposes.
    Track the TTF path actually loaded by _load_font on self._font_path
    so _draw_dot_circle can re-use it for the size-3 active-dot number.
    Previously self._font_path was never assigned; the AttributeError
    was swallowed by the broad except and every active-dot number fell
    back to Pillow's bitmap default — restoring the intended monospace
    rendering as a side effect of the type fix.
    [eink_display.py]
2026-05-13 Move staleness override into check_for_new_episodes
    The main loop no longer computes staleness or forwards a `force` flag;
    the scheduled callback decides for itself whether to defer or force a
    check. Fewer moving parts in the polling loop.
    [podcast_player.py]
2026-05-18 Document installation, hardware parts, and wiring
    Add Installation section to README covering apt-based deps and optional
    e-ink setup. Add HARDWARE.md (bill of materials) and WIRING.md (GPIO pin
    assignments) and link both from the Hardware Setup section. Note the
    in-car FM transmitter as the recommended audio output.
2026-05-18 added 3d files and pictures from thingyverse
    [raspi_box_base.FCStd, raspi_box_the_box.step, raspi_box_the_box.stl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]
2026-05-18 Rename 3d_files/ to enclosure/ and link from README
    [raspi_box_base.FCStd, raspi_box_the_box.step, raspi_box_the_box.stl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]
2026-05-18 Tighten enclosure links and size frontview image
2026-05-18 Restructure README: add overview, expand hardware/usage sections
    - Add "How it works" intro so first-time readers see the controls and modes up front
    - Replace single Hardware Setup link list with a parts list, separated Enclosure section
    - Document LED meanings, mode switch behavior, and status.py / led_controller.py smoke tests
    - Use <your-user> placeholders in the systemd unit and fix grammar
2026-10-06 fixxing bug where new episode inherited previous episode's playback position by making sure the episode did not change before when saving position
    [podcast_player.py]
